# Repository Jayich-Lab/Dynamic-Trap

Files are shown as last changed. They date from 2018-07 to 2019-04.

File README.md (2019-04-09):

A video explaining and displaying the demonstration (click to watch):

Ion Trapping Demo (https://www.youtube.com/watch?v=MBt415qsYS0 "Mechanical Ion Trap Demonstration")

# Dynamic mechanical trap
Ion traps hold charge particles such as atoms or molecules that are missing an electron (they are "ionized").  They are powerful tools for quantum information science, precision optical timekeeping, quantum chemistry, nuclear physics, and even particle physics.  One type of ion trap, a Paul trap named after the Nobel Laureate  [Wolfgang Paul](https://en.wikipedia.org/wiki/Wolfgang_Paul), traps charged particles with a combination of static and dynamic electric fields.  The dynamic electric field that traps the ions is a bit difficult to visualize.  The mechanical analogue of the electric trap that we have developed in this repository helps one understand the forces and fields present in an ion trap.

The mechanical dynamic trap illustrates how oscillating electric fields can create a saddle point potential for a charged particle. In this case the "charged particle" is a ball, and by adjusting the rotational speed of the trap one can get a sense for how an ion is trapped in oscillating electric fields.

The trap build outlined in the [Guides](https://github.com/Jayich-Lab/Dynamic-Trap/tree/master/Guides) directory of this repository help bridge our research in the quantum regime, to something that you can recreate mechanically.  We have included all the files you need to make a dynamic trap, shown below, and background materials that hopefully prove helpful if you use this in a scientific demonstration.  We strongly believe in open science, and the license is intended to reflect that.  Please use the materials found in this repository however is most suitable to your needs.  

Mechanical Trap

If you are interested in learning more about our research, visit our [lab's website](http://jayich.io/).

# Supplmental Information
Resources on a mechanical analogue to the quadrupole ion trap.

The stp file for the trap surface (saddle) is ready to print -- simply import into MakerBot Print and print.

The base is specific to the motor we used, a Uxcell gearbox motor. Modifications will be necessary if a different motor is used.

The mounting ring is used for mating the saddle to the D-shaped motor shaft. It fits a motor shaft with 6mm diameter with a 0.5mm (at thickest point) flat cut.

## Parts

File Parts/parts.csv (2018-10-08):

Part | Quantity | Price
Motor Speed Controller (Adafruit DRV8871) | 1 | $7.50
DC Motor | 1 | $5
3D Printed Saddle | 1 | $1
3D Printed Motor Mount | 1 | $1
Ball | 1 | $1

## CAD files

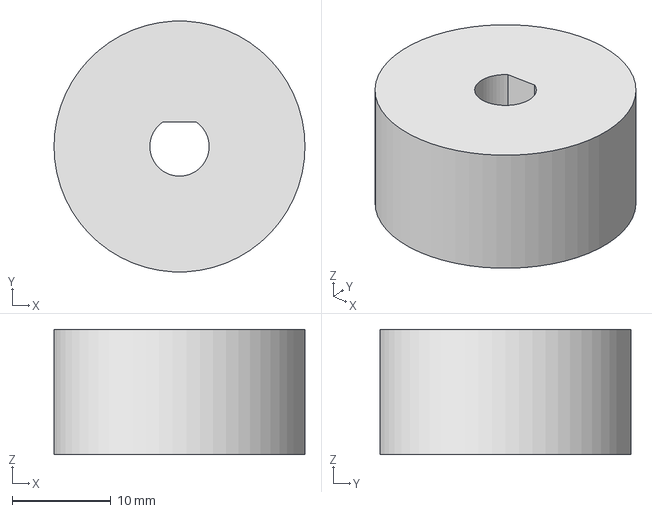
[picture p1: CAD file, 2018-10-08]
Parts/joinRing.stp
25.4 x 25.4 x 12.7 mm

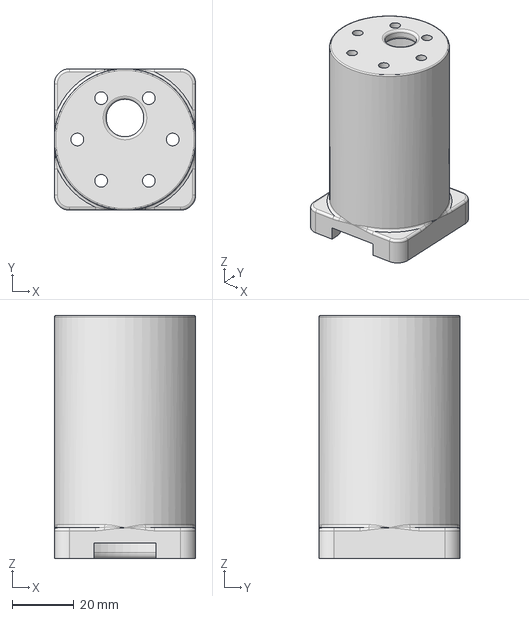
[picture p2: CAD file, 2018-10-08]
Parts/base_version4.stp
46.0 x 46.0 x 79.0 mm

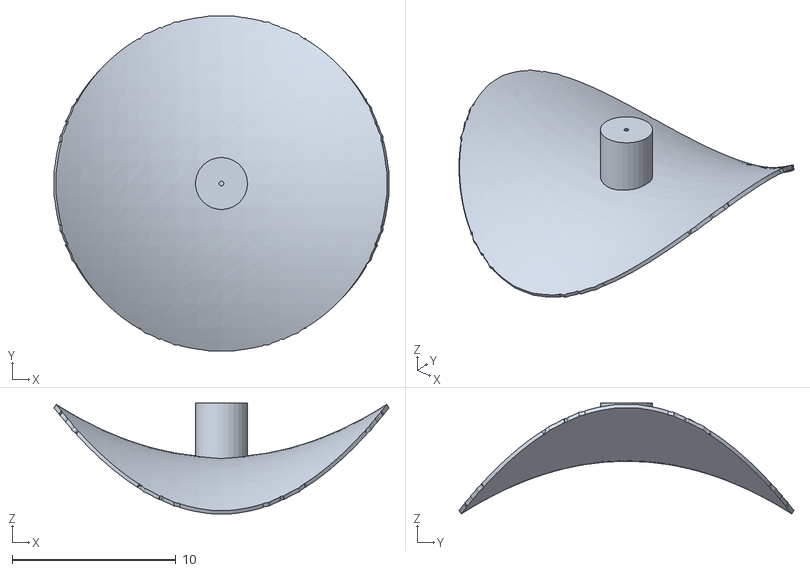
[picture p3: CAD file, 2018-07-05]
Parts/saddle_model.stl
20.5 x 20.5 x 6.78

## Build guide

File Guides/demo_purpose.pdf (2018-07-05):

http://jayich.io/ | Ion Trapping Demo | Jayich Lab

## The ion trap analogue as a teaching tool:

- Motivates thinking about atoms and ions:

– Motivates thought about the size of atoms.

– Introduces to and motivates thinking about ions and charge.

– Motivates interest in physics in general.

- Construction of the trap:

– Creates opportunity to generate interest in and experience with 3D printing, use of Makerspaces: ∗ Explores various aspects of 3D printing – layer resolution, how to create smooth parts, how to print things with support, etc.

– Provides exercise in circuits for digital control of motor speed.

– Provides exercise in coding for programming of microcontroller.

- Introduces students to the goals of atomic physics research:

– Motivates why atomic physics research is important:
∗ To atomic clocks – important to GPS.
∗ To quantum computing – exciting forefront in computational problem solving.
- Introduces students to the concepts of ion trapping.
- Introduces students to measurement techniques: e.g., for the measurement of the motor speed.

– Can be done by eye and stopwatch:
∗ Creates teaching opportunity about significant figures and measurements.

– Can be done with light/laser, mirror, and photodetector:

∗ Creates opportunity to explore coding applications, programming microcontroller to count light pulses (rotations).

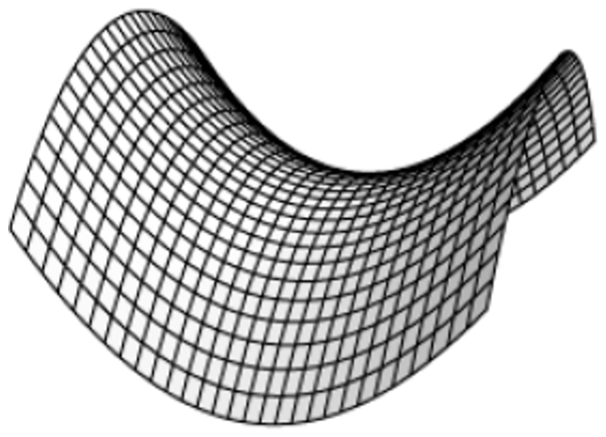
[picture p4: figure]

1

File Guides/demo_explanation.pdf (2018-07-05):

http://jayich.io/ | Ion Trapping | Jayich Lab

## What is ion trapping, and how does it work?

In order to study atoms, we need to hold them in place in the lab. This is the purpose of the ion trap.

Atoms, of course, are incredibly small, which makes this task difficult – since they are so small, tiny disturbances could knock them free if not properly accounted for. We thus need to make sure they can’t escape. How do we do this?

A particle is “trapped” if it can be imagined to be at the bottom of a “bowl,” so that if it gets pushed in any direction, the particle will “roll” back to the center and remain trapped in the bowl. An example is shown below:

As if the size of the atoms didn’t make our job hard enough, the laws of electromagnetism forbid us from making a perfect “bowl” trapping potential. The best we can do is to make a saddle-shaped potential, such as the following:

If you imagine putting a ball at the center, it would begin to roll down the downhill part of the saddle, eventually escaping the trap – this clearly does not work for our purposes! To get around this problem, physicists have come up with a clever solution, which works as follows:

As the ball begins to roll down the downhill part, we fold it upward to “catch” the ball! The shape must remain a saddle, so the previously uphill part folds into a downhill region. The ball will then roll down the new downhill, at which point we invert the saddle again, once more “catching” the ball. When this “flapping” of the saddle is done at the right rate, the ball will remain trapped in the center of the saddle.

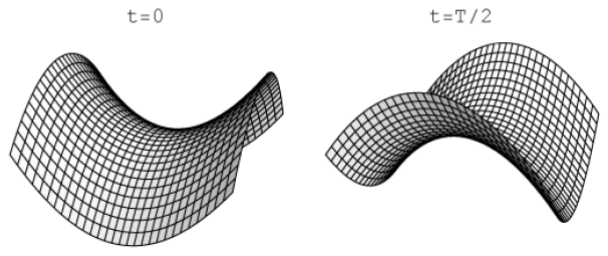
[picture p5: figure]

To make this easier to visualize, a rotating saddle can be used as an analogy to the alternating “uphill” and “downhill” regions of an ion trap. We have prepared a teaching demo of such a setup that can easily be 3D printed and assembled for classroom use.

1

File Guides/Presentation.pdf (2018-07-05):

# Ion Trapping and its Mechanical Analogue

# 2D Quadrupole Ion Trapping

Earnshaw’s Theorem: Gauss’s law states that in region with zero charge density, div(E)=0, and so it is impossible to create stable equilibrium point.

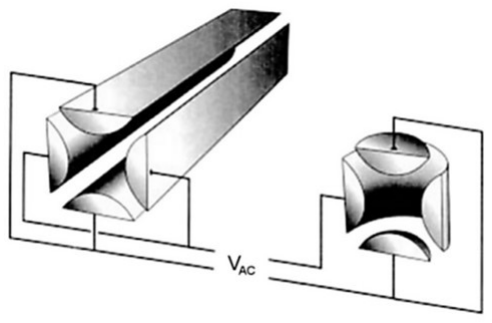
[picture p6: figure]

Potential oscillates between trapping and anti-trapping, with the different axes remaining 180 degrees out of phase. For oscillation of certain frequency, as an ion subject to potential begins to move along an anti-trapping axis, the anti-trapping potential along that axis switches to trapping, thereby “catching” the ion.

The best one can do is create a saddle potential (top right) – trapping along one horizontal axis and anti-trapping along the other. Examples of electrodes used to generate these potentials are shown at lower right, with a 2D quadrupole trap (to be discussed here) on the left, and a 3D quadrupole trap on the right.

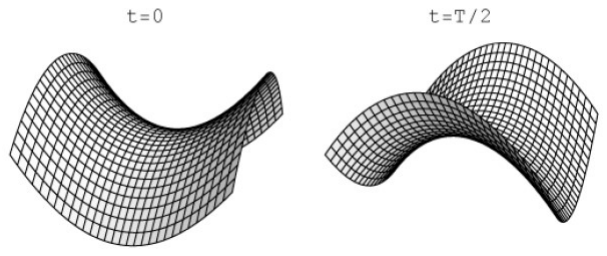
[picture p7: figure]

# The Quadrupole Trap Potential

With the DC bias set to zero, a 2D trapping
potential with frequency , trap depth URF, and
radius r0

, takes the simplified form:

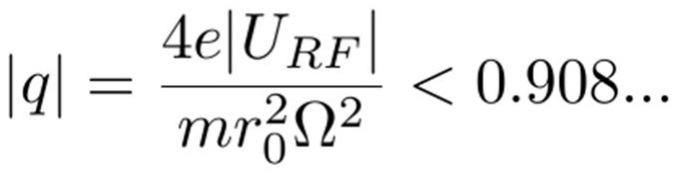
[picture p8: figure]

Equations of motion are Mathieu equations -- solutions not analytic, but are either stable/bound oscillatory solutions or exponentially growing unstable solutions. In this case, “largest region of stability is given by the [following requirement]”:

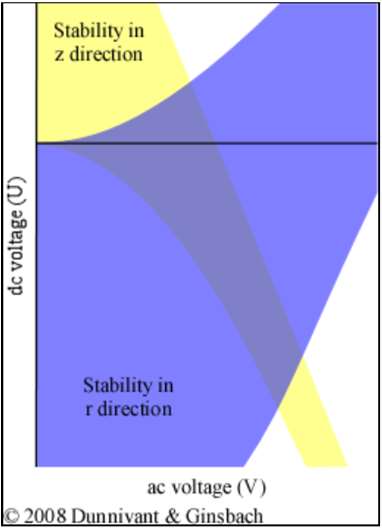
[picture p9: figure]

Need to choose frequency and URF according to m, e, and r0 (physical characteristics of ion and trap) to satisfy stability condition.

Regions of stability in r and z are mapped out in a stability diagram (basic example at right), and parameters are chosen such that the regions of stability overlap in each dimension. Axes of diagram are dependent on RF amplitude and DC bias (in our example, set to 0).

# The Mechanical Analogue

Electric saddle potential can be visualized as a saddleshaped surface – i.e., the following gravitational potential:

Oscillating behavior of trapping and anti-trapping regions is achieved by rotation of the saddle. If saddle rotates with frequency , then in lab frame coordinates (x,y), the potential takes the following form:

Height of the trap h0

serves as analogue to the RF potential depth from the electric case, and r0

is again
the radius of the trap. The dependence on 2 is due to the symmetry under Rz

() of the potential.
Difference from the electric case is obvious, and results from the trap rotating, rather than inverting or (“flapping”) – the cross-term results in the potential being present for all t, rather than going to zero periodically as in the case of (x,y,t).

# Stability of the Mechanical Trap

The equations of motion for a mass in the frictionless mechanical trap in are analytic, and are either stable/bound oscillatory or exponentially growing solutions. To ensure behavior which is stable, the following condition must be
satisfied:
Note the lack of dependence on mass – it cancels out due to U(x,y) m.

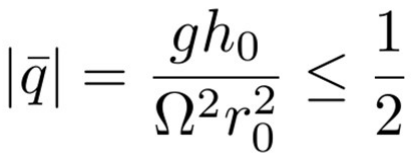
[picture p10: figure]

For small q (~ less than 0.15), the potential is well-approximated by a time average of U(x,y,t) – time
averaged position of particle (secular motion) then resembles a harmonic oscillator with frequency q. Stability seems to depend only on trap parameters, and not on initial conditions of the mass (with exception to

the r=0, v=0 case) – any trap satisfying the stability condition is predicted to have infinite trapping lifetime. Barring a failure to satisfy the above inequality, the lifetime is constrained by the presence of friction.

This behavior is explained by introducing friction – friction contributes a real exponential factor to the motion of the particle, leading to finite trapping lifetime proportional to the coefficient of friction in the system.
With friction added in, the particle lifetime can be calculated in terms of the initial starting position r=R, and is seen to depend on a factor ln(r0

/R) – the trap lifetime is greatly increased by placing the mass closer to the center of the trap.

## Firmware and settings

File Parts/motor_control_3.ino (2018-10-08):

int pwmPin = 9;

void setup() {
  Serial.begin(9600);
  pinMode(pwmPin,OUTPUT);
  analogWrite(pwmPin, 150);
  delay(300);
}

void loop () {
  int potValue = analogRead(A0);

  int newpotValue = map(potValue, 0, 1023, 255,
  0);

  
  analogWrite(pwmPin, newpotValue);
  
  Serial.println(map(newpotValue,0,255,100,0));
}

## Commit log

2018-07-05 completed saddle model for printing
    [saddle_model.stl]
2018-09-29 Add files via upload
    added motor control file with fix
    [motor_control_3.ino]
2018-09-29 Step file for printing -- Print this one
2018-09-29 Ring for joining D-shaped motor shaft to saddle
    [joinRing.stp]
2018-09-29 base which holds motor
    31mm PCD, used for motor w/ 37mm diamter (uxcell 1000rpm gearbox motor)
    [base_version4.stp]
2018-10-08 update
    update
    [base_version4.stp, joinRing.stp, parts.csv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]
